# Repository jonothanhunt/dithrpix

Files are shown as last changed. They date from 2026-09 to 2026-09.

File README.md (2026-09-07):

<p align="center">
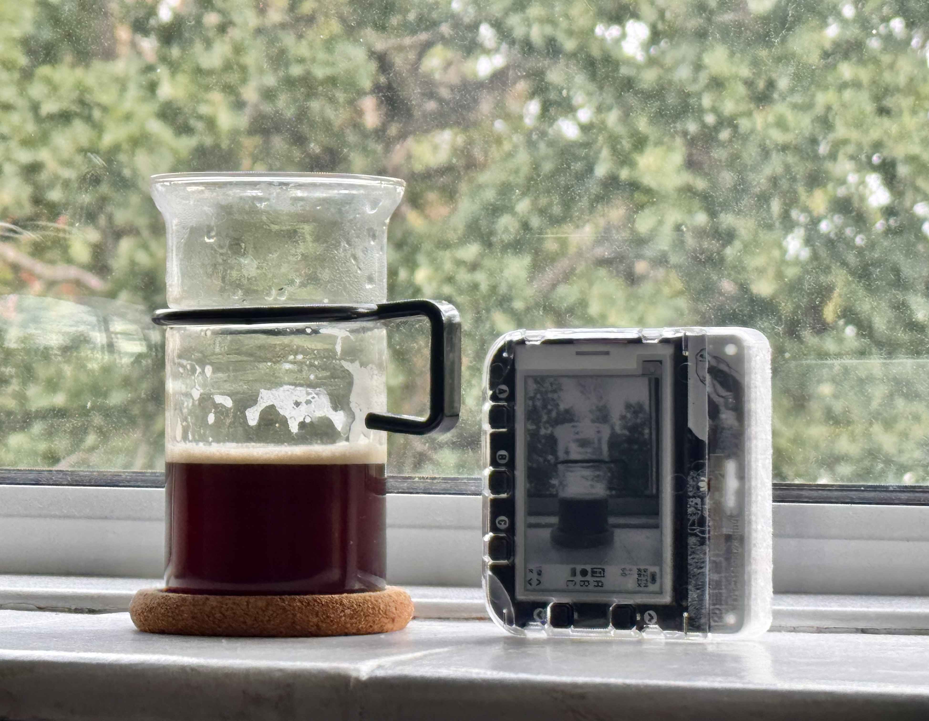
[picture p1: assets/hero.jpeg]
DITHRPIX Hero
  
</p>

<h1 align="center">DITHRPIX</h1>

<p align="center">
  
  
  
</p>

<p align="center">
  <strong>A four-shade greyscale dither camera.</strong><br/>
  Built with the <a href="https://shop.pimoroni.com/products/badger-2350">Pimoroni Badger 2350</a> and a PTC06 TTL serial JPEG camera connected to the Qw/ST port, powered by Pimoroni's <a href="https://badgewa.re/docs">Badgeware API</a>.<br/><br/>
  📖 <strong><a href="https://jonothan.dev/blog/dithrpix">Read the story behind the build on my blog</a></strong>
</p>

<div align="center" style="line-height: 0;">
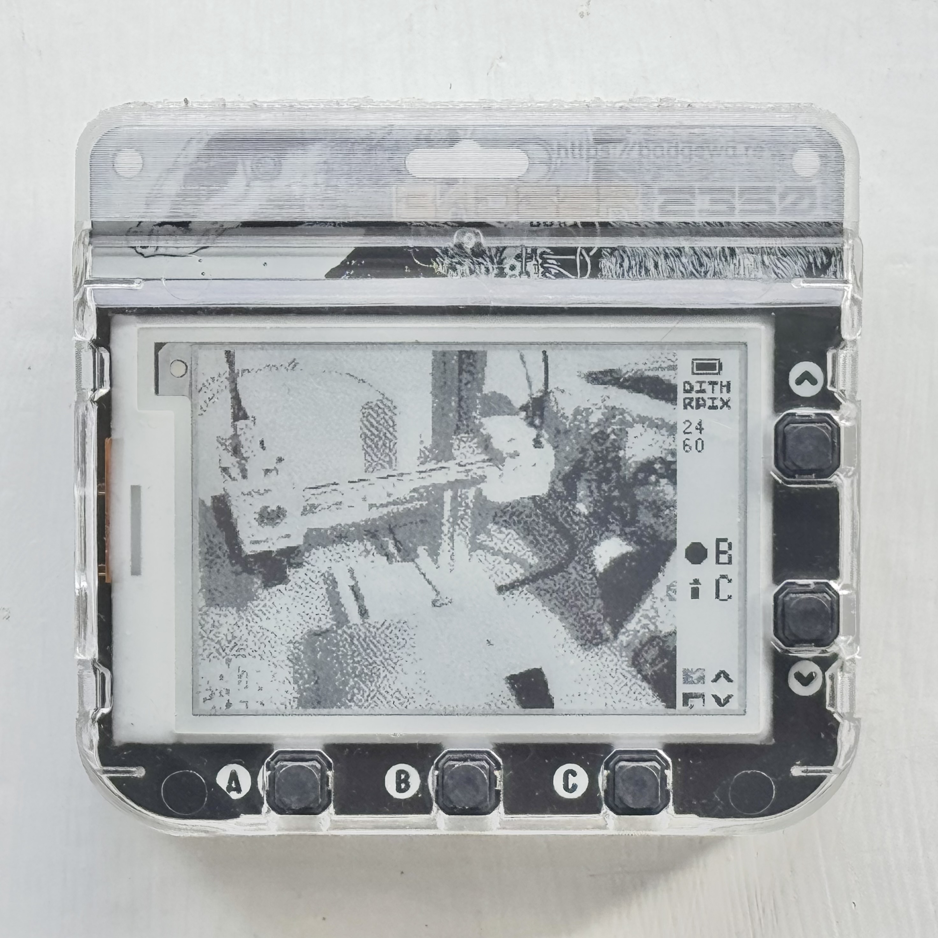
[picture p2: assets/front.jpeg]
Front view
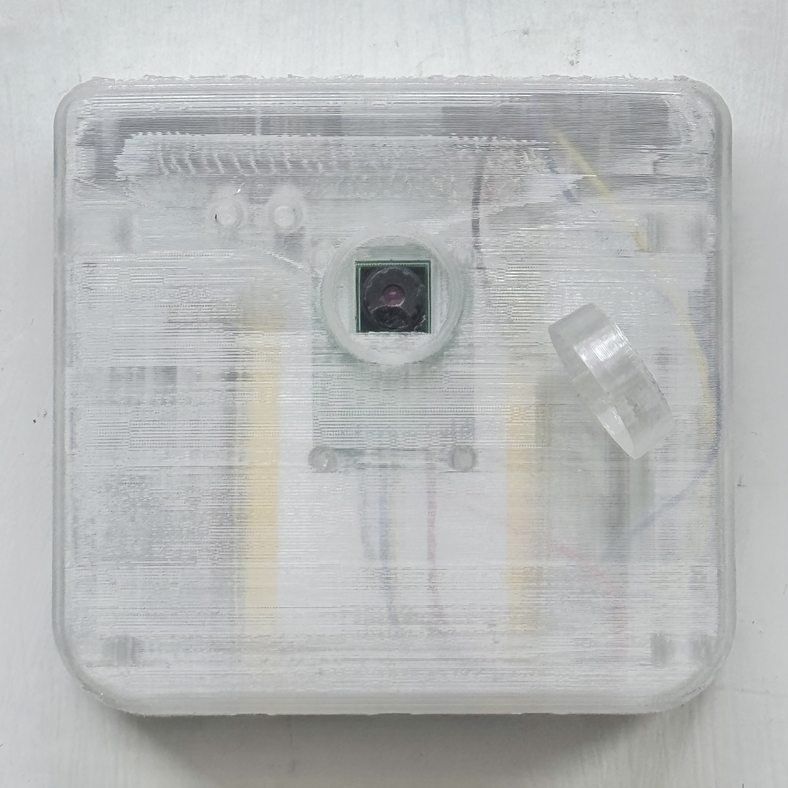
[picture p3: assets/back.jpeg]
Back view
  <br>
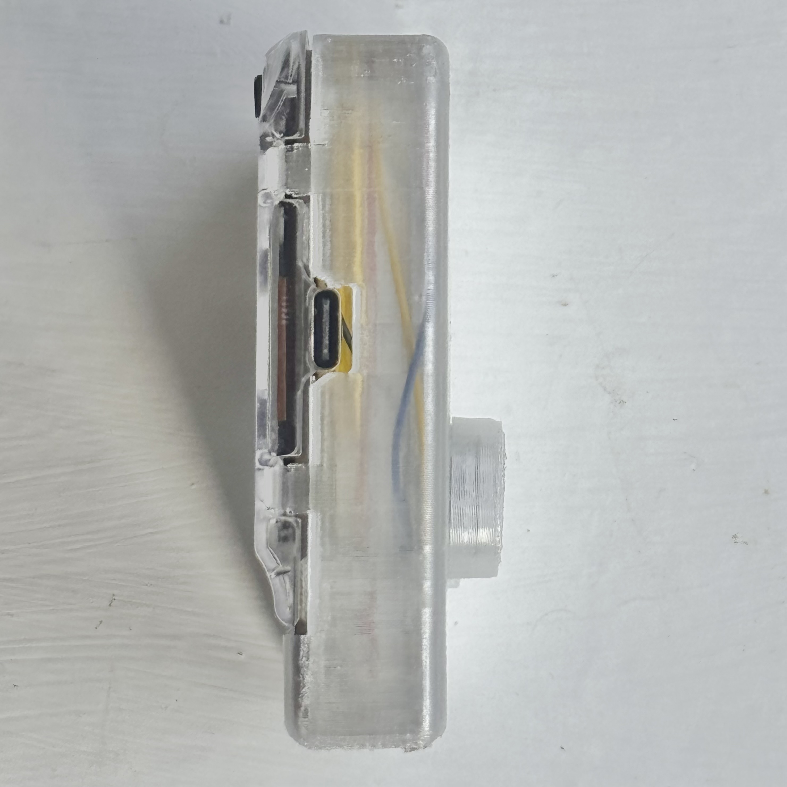
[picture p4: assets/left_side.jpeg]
Left side view
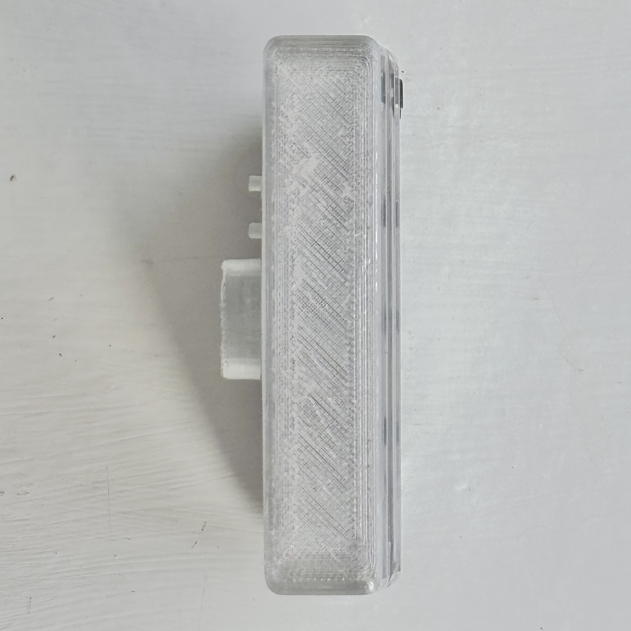
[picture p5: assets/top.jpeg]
Top view
  <br>
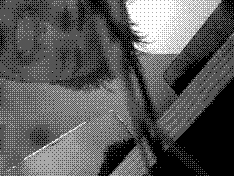
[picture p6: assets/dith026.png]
Example photo 1
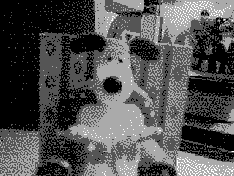
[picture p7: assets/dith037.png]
Example photo 2
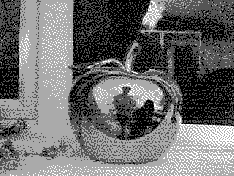
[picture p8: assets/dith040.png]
Example photo 3
  <br>
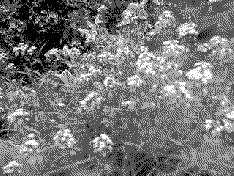
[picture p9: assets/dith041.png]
Example photo 4
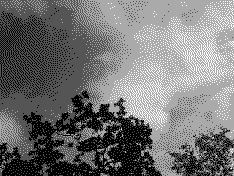
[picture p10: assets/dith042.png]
Example photo 5
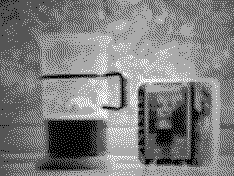
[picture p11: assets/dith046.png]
Example photo 6
  <br>
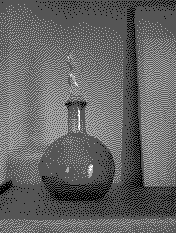
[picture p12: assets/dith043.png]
Portrait example 1
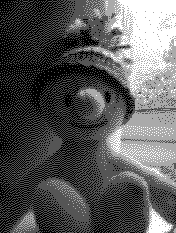
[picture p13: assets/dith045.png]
Portrait example 2
  
</div>

## Table of Contents
1. [Features](#features)
2. [Guide](#guide)
3. [Controls](#controls)
4. [Project Structure](#project-structure)
5. [Contributing](#contributing)
6. [License](#license)

## Features
- **Photos:** Camera module captures at 320x240, downsampled into the panel's 234x176 view (and saves byte-for-byte exactly what is on the screen).
- **Tone modes:** The camera handles exposure automatically, so these four modes act as a post-processing style. They let you select which slice of the incoming range gets stretched across the display's four shades:
  - **A (All):** Maps the full input range (0–255).
  - **H (High):** Stretches the darkest 50% (0–128), resulting in a brighter image.
  - **M (Mid):** Stretches the middle 50% (64–192), boosting overall contrast.
  - **L (Low):** Stretches the brightest 50% (128–255), resulting in a darker image.
- **Dither modes:** Bayer 4x4 ordered, Floyd-Steinberg, Atkinson, and flat posterise (the selected mode is shown as a cute mini swatch on the screen next to C).
  <div align="center" style="line-height: 0;">
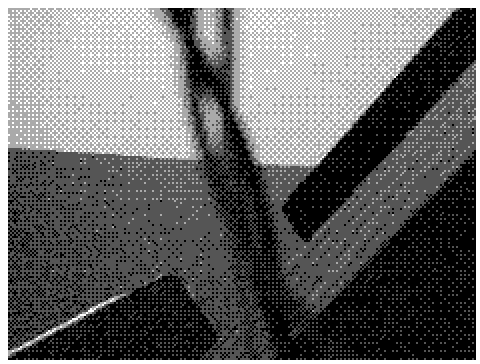
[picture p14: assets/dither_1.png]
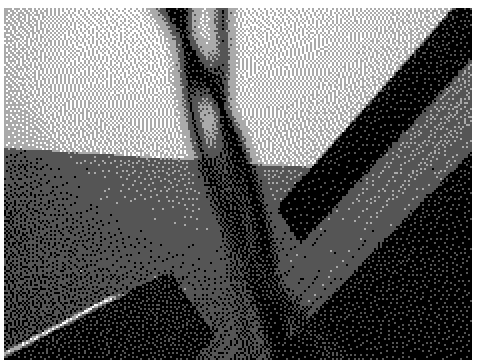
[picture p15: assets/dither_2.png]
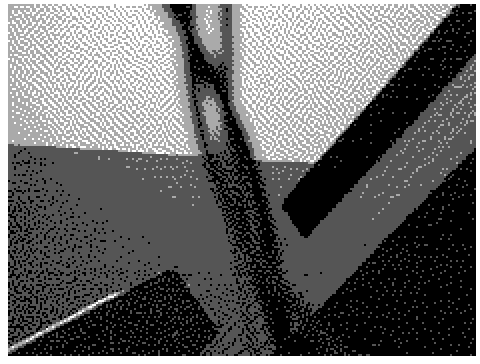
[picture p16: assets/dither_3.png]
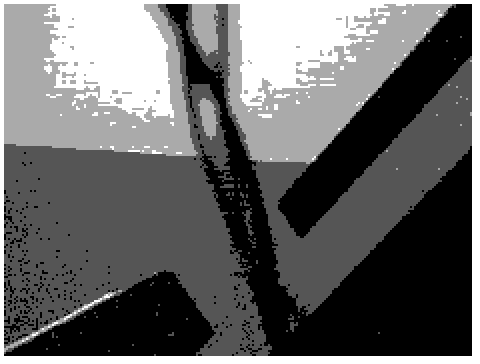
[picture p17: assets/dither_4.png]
    
  </div>
- **Gallery storage:** Safely stores up to 60 photos (fits in 1MB LittleFS storage available to apps).
- **Indexed PNG exports:** Files are saved as uncompressed 2-bit indexed PNGs matching the hardware palette (`[0, 85, 170, 255]`).

## Guide

### 1. Hardware Prep
- [Pimoroni Badger 2350](https://shop.pimoroni.com/products/badger-2350?variant=55801169707387) (running [Badgeware v3.0.2 or later](https://badgewa.re/docs/introduction/update-your-firmware.md)).
- [PTC06 TTL serial JPEG camera](https://thepihut.com/products/miniature-ttl-serial-jpeg-camera-with-ntsc-video?variant=27739329809).
- [Qw/ST (JST-SH) to bare wire cable](https://thepihut.com/products/stemma-qt-qwiic-jst-sh-4-pin-to-premium-male-headers-cable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).
- Tiny M1 screws.

Solder the Qw/ST cable to the camera's power and serial pads, then connect it to the Badger 2350's Qw/ST port.

<div align="center">
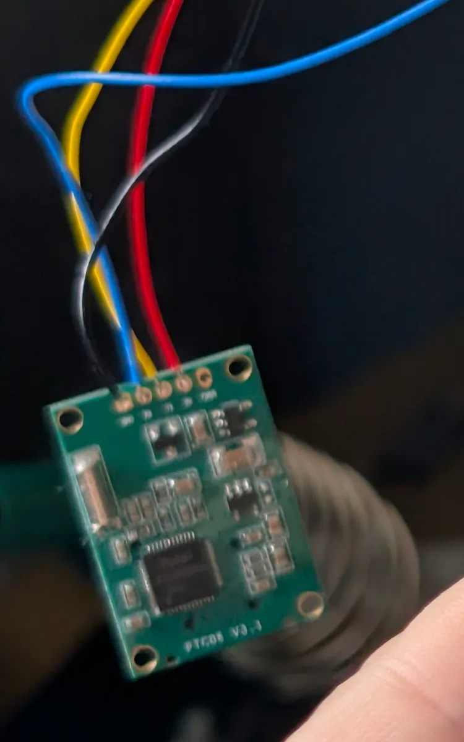
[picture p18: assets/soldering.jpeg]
Soldered camera module
  
</div>

### 2. Software Installation
Install alongside existing Badger apps, or replace the main launcher to boot directly into the camera.

1. Put the badge into disk mode (press **RESET** twice).
2. Wait for it to mount as `BADGER`.
3. Copy the application files:
   ```bash
   # Copy the camera app directory
   cp app/dithcam/*.py app/dithcam/icon.png /path/to/BADGER/apps/dithcam/
   
   # Optional: Replace the default launcher to boot directly to the camera
   cp boot/main.py /path/to/BADGER/main.py
   ```
4. Sync and unmount the drive before resetting:
   ```bash
   sync
   udisksctl unmount -b /dev/sda
   ```
5. Press **RESET** on the badge to test the software.

### 3. Assembly

<div align="center">
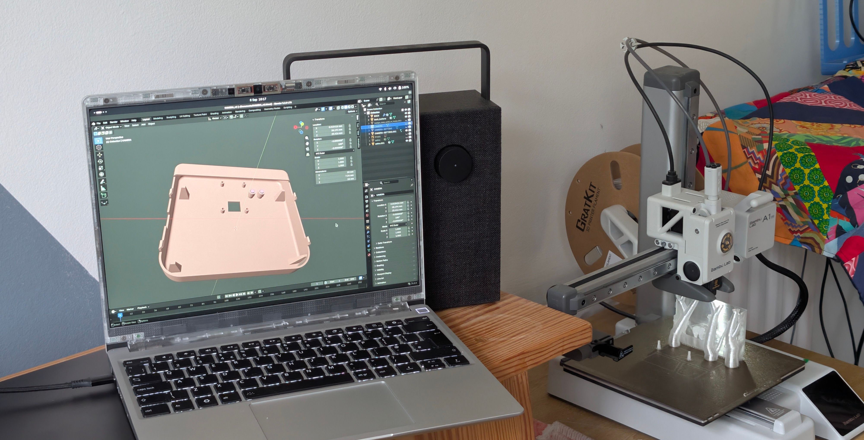
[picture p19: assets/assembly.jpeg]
Assembled DITHRPIX camera
  
</div>
<br>

Once you have tested the camera, print the back case which replaces the factory one. I used [GratKit clear PETG](https://gratkit.com/products/gratkit-petg-3d-printing-filament-1-75mm-basic-petg-1kg?variant=40792277745744) for the print.

The .stl for printing is here: [`hardware/DITHRPIX_BACK_CASE.stl`](hardware/DITHRPIX_BACK_CASE.stl)

I recommend printing the case upside down for a balance between supports and strength.

*Note: The case mounts the camera upside-down for clearance, so the app applies a 180-degree rotation by default to compensate.*

### 4. Managing Photos
First, connect the badge to your computer via USB. Ensure it is powered on and in its normal running state (not disk mode) so that `mpremote` can communicate with it over serial.

To pull your photos off the badge, you can use `mpremote`:
```bash
mpremote cp -r :photos/ ./my-photos/
```

To wipe the gallery and reclaim space on the 1MB partition, run:
```bash
mpremote exec "import os; [os.remove('photos/' + f) for f in os.listdir('photos')]"
```

## Controls

| Button | Camera Mode | Gallery Mode |
| --- | --- | --- |
| **A**  | Cycle tone mode | — |
| **B**  | Take a photo | Back to camera |
| **C**  | Cycle dither mode | Delete photo (asks first) |
| **UP** | Open gallery | View older photo |
| **DOWN** | Refresh the preview | View newer photo (or back to camera) |

## Project Structure

```text
dithrpix/
├── app/dithcam/     # The application (installed to /system/apps/dithcam)
├── boot/main.py     # Boot script (installed to /system/main.py)
├── hardware/        # 3D models and physical design files
└── tools/           # Probe scripts used for testing hardware behaviors
```

## Contributing

Feedback, ideas, and PRs are super welcome! Whether you want to add a new dither mode, tweak the UI, or just fix a typo, feel free to jump in and open an issue or pull request.

## License

MIT © 2026 Jonothan Hunt — see [LICENSE](LICENSE) for the full text.

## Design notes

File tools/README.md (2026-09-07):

# Probes

Run against the badge in normal mode (not disk mode), with the REPL available:

```bash
mpremote connect /dev/ttyACM0 run tools/probe_power.py
```

`mpremote run` executes the script on the device without writing anything to
it. Each probe prints its findings; several also leave files on `/` for pulling
back with `mpremote ... fs cp`.

| Probe | Question it answers | Outcome |
| --- | --- | --- |
| `probe_power.py` | What sleep/wake/power API exists? | Found `powman`'s wake reasons — the fix for battery wake |
| `probe_downsize.py` | Does the camera's downsize work? | Misleading: wrote to the *read* register |
| `probe_downsize2.py` | Retry with the datasheet's detailed opcodes | Also wrong; the docs contradict themselves |
| `probe_raw.py` | What do 0x53/0x54/0x55 actually do? | Settled it: downsize is not implemented |
| `probe_settle.py` | Is `frame_length` read too early? | No — but exposed the 8-byte truncation |
| `probe_ab.py` | 160x120 vs 320x240, same scene | 320x240 carries ~4x the detail |
| `probe_stable.py` | Is 320x240 stable? Does `blit` average? | Stable; `blit` is nearest-neighbour |
| `probe_startup.py` | Which camera init step is slow/failing? | Full init ~1.8s, frame ~1.4s |
| `probe_hang.py` | Is the camera or the dither blocking? | Neither — both fine |
| `probe_scale.py` | Does `blit` average when shrinking? | **Crashes the board** — allocates 307KB and scans it in pure Python |
| `probe_dither.py` | Which firmware dither filters are usable? | **Crashes the board** — guesses native signatures |

The last two are kept as cautionary examples. `probe_dither.py` in particular
calls native functions with invented argument lists, which hard-faults rather
than raising — do not run it without reading it.

`pull_photos.sh` copies the photos off `/`, which disk mode cannot see.

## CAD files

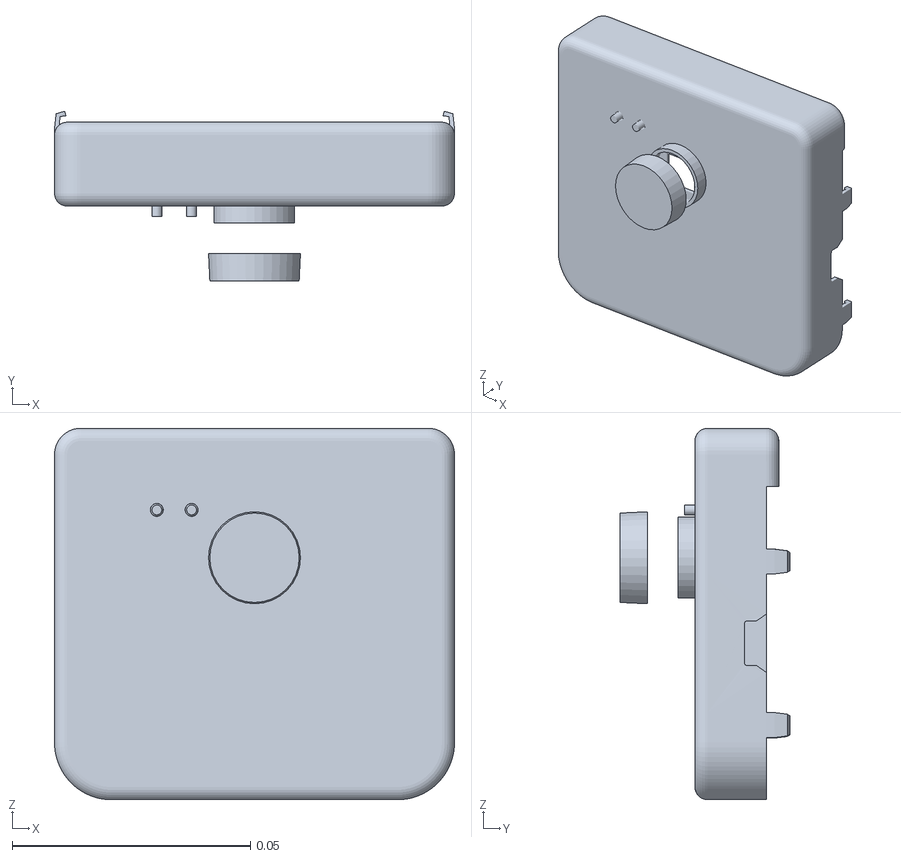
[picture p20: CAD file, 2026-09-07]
hardware/DITHRPIX_BACK_CASE.stl
0.0839 x 0.0356 x 0.078

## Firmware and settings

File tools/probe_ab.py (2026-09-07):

# A fair A/B of the same scene at 160x120 and 320x240, using a corrected
# frame read.
#
# Two things learned from the earlier probes:
#   * DOWNSIZE_CTRL echoes back in its status register but does not change the
#     actual output size without a reset - the frame stayed at 3652 bytes
#     whether we asked for 640x480, 320x240 or 160x120. So 0x54 is the same
#     register set_image_size already writes, by another route, and the "fast
#     preview, full capture, no reset" plan is off.
#   * read_frame drops the final 1-7 bytes whenever the frame length is not a
#     multiple of 8, which eats the JPEG's EOI marker. 3652 % 8 == 4, so every
#     frame in that probe came back truncated. That is a live bug in the app.
#
# Hold the camera still - the two shots are seconds apart and are meant to be
# the same scene.
import sys
import time

sys.path.insert(0, "/system/apps/dithcam")
from machine import UART, Pin
import vc0706
from vc0706 import VC0706, CameraError

READ_FBUF = 0x32


def uart(baud):
    return UART(1, baudrate=baud, tx=Pin(4), rx=Pin(5), timeout=1000, rxbuf=2048)


def find_camera():
    for baud in (115200, 38400):
        c = VC0706(uart(baud))
        try:
            c.version()
            return c
        except CameraError:
            pass
    raise SystemExit("no reply at either baud")


def read_frame(c, length, chunk=256):
    """As the driver's, but the tail is read rounded UP to the next multiple
    of 8 and then trimmed, rather than dropped. The alignment rule is about
    the transfer, not the payload, so over-reading into the frame buffer is
    harmless - whereas under-reading loses the end of the JPEG."""
    out = bytearray()
    addr = 0
    while addr < length:
        want = min(chunk, length - addr)
        n = (want + 7) & ~7                 # round up, never down
        payload = bytes([0x00, 0x0A,
                         (addr >> 24) & 0xFF, (addr >> 16) & 0xFF,
                         (addr >> 8) & 0xFF, addr & 0xFF,
                         (n >> 24) & 0xFF, (n >> 16) & 0xFF,
                         (n >> 8) & 0xFF, n & 0xFF,
                         0x00, 0x0A])
        c._send(READ_FBUF, payload)
        head = c._read_exact(5)
        if len(head) < 5 or head[0] != 0x76 or head[3] != 0x00:
            raise CameraError("fbuf @%d" % addr)
        data = c._read_exact(n)
        if len(data) != n:
            raise CameraError("fbuf @%d short %d/%d" % (addr, len(data), n))
        out.extend(data)
        c._read_exact(5)
        addr += want
    return bytes(out[:length])              # trim the over-read tail


def configure(size):
    c = find_camera()
    c.color_mode(2)
    c.set_image_size(size)
    c.reset()
    time.sleep(2.5)
    c = VC0706(uart(38400))
    c.set_baud(115200)
    c = VC0706(uart(115200))
    c.version()
    return c


def shot(c, tag):
    c.take_picture()
    length = c.frame_length()
    t0 = time.ticks_ms()
    data = read_frame(c, length)
    ms = time.ticks_diff(time.ticks_ms(), t0)
    c.resume()
    with open("/ab_%s.jpg" % tag, "wb") as f:
        f.write(data)
    print("  %-8s %6d B  read %5d ms  len%%8=%d  EOI %s"
          % (tag, len(data), ms, length % 8,
             "yes" if data[-2:] == b"\xff\xd9" else "NO"))


print("160x120 (what the app does today)")
cam = configure(vc0706.SIZE_160x120)
shot(cam, "160")

print("320x240 (same scene - hold still)")
cam = configure(vc0706.SIZE_320x240)
shot(cam, "320")

print("back to 160x120 for the app")
cam = configure(vc0706.SIZE_160x120)
cam.power_save(True)
print("done")

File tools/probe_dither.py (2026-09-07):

# What dithering does this firmware actually offer, and can each option be
# pinned to our four shades?
#
# The rule the whole app rests on is that a photo is stored exactly as the
# panel shows it, so any algorithm we offer must land on [0, 85, 170, 255] and
# nothing else. The stylised filters (c64, cga) probably impose their
# own palettes - which would break that - so every candidate is checked by
# looking at the values it actually produces, not by its name.
#
# Also renders a gradient swatch at the size the rail cell would use, to see
# whether a pattern is even legible that small.
import picovector as pv

SHADES = [0, 85, 170, 255]
PALETTE = [pv.color.rgb(v, v, v) for v in SHADES]
W, H = 64, 32                   # big enough to judge the pattern
CELL_W, CELL_H = 11, 14         # the actual rail cell


def gradient(w, h):
    """A left-to-right ramp: every input level appears, so a dither has
    something to work with at all four shades."""
    im = pv.image(w, h)
    for x in range(w):
        v = int(255 * x / max(w - 1, 1))
        im.pen = pv.color.rgb(v, v, v)
        im.rectangle(x, 0, 1, h)
    return im


def values(im, w, h):
    raw, stride = im.raw, im.stride
    seen = set()
    for y in range(h):
        base = y * stride
        for x in range(w):
            seen.add(raw[base + x * 4])
    return sorted(seen)


print("candidate filters on an image instance:")
probe = pv.image(4, 4)
for name in ("dither", "palette_dither", "onebit", "monochrome", "threshold",
             "duotone", "c64", "cga", "contrast", "window", "invert"):
    print("  %-16s %s" % (name, "yes" if hasattr(probe, name) else "no"))

print()
print("calling each, and checking what values come out")
print("(anything other than [0, 85, 170, 255] cannot be stored as-is)")


def attempt(label, apply):
    im = gradient(W, H)
    try:
        apply(im)
    except Exception as e:
        print("  %-34s %s: %s" % (label, type(e).__name__, e))
        return
    got = values(im, W, H)
    ok = got == SHADES
    print("  %-34s %-2d values %s %s"
          % (label, len(got), got[:8], "<- ours" if ok else ""))


for strength in (0, 64, 128, 255):
    attempt("palette_dither(SHADES, %d)" % strength,
            lambda im, s=strength: im.palette_dither(PALETTE, s))

for args in ((), (PALETTE,), (PALETTE, 128), (4,), (128,)):
    attempt("dither%s" % (args,), lambda im, a=args: im.dither(*a))

attempt("onebit()", lambda im: im.onebit())
attempt("monochrome()", lambda im: im.monochrome())
attempt("threshold(128, 0, 255)", lambda im: im.threshold(128, 0, 255))
attempt("c64()", lambda im: im.c64())
attempt("cga()", lambda im: im.cga())

print()
print("swatch legibility at the rail cell size (%dx%d):" % (CELL_W, CELL_H))
sw = gradient(CELL_W, CELL_H)
sw.palette_dither(PALETTE, 128)
raw, stride = sw.raw, sw.stride
for y in range(CELL_H):
    row = "".join(" .:#"[SHADES.index(raw[y * stride + x * 4])]
                  if raw[y * stride + x * 4] in SHADES else "?"
                  for x in range(CELL_W))
    print("    |%s|" % row)
